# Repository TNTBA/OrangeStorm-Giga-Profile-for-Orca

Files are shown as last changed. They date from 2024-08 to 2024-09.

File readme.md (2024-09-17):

# System profile for Orca Slicer
orca-screenshot

# 9/17/2024 - I have decided to stop working on this project. Elegoo has a fork of Orcaslicer which has print profiles which are much better than what you'll find here. Check it out: https://github.com/ELEGOOTechSupport/ElegooSlicer  Read more here: https://tntba.com/giga-tap-orangestorm-giga-probe-mod/

**Currently this profile works ONLY after making changes to your printer.cfg file in klipper.**
**This is only for Elegoo Printers who are using a single hotend. If you are using more than one hotend (IDEX configuration), do not use this configuration.** 

Enter into Fluidd (the UI for your printer/klipper) so you can access klipper and your config files. 

To do this, you would go to your computer's browser and enter the ip address for your 3d printer. Your printer's ip address can be found by looking at the printer's screen in a config section somewhere. 

ex. 192.168.xxx.xxx/#

After logging in, go to your printer's configuration tab. 

Find your "printer.cfg". right click the file and rename it. You should rename to something like: "printer-elegoo.cfg". we do not want to delete this because you may want to go back to this if you dont like my printer.cfg. 

download the included printer.cfg from this github and upload it to fluidd. This will act as your new config file. 
download the orca_variables.cfg from this github and upload it to fluidd.

if everything is uploaded, restart klipper from the Fluid UI screen. 

# WINDOWS INSTALLATION:
## ORCA SLICER PROFILE INSTALLATION INSTRUCTIONS
You will need the following files to make this work:

### Main Manufacturer Config file:
#### 1. orca_slicer_config\profiles\Elegoo.json

On windows:You will require admin privileges in order to do this.  Go to "C:\Program Files\OrcaSlicer\resources\profiles" from windows explorer. You will see there is already an "Elegoo.json". Rename this file as "Elegoo original.json" or save it in another location on your computer in case you wish to revert back one day. Save the Elegoo.json file from this github to that location. 

### Build Plate SVG & STL
#### 1. orca_slicer_config\profiles\Elegoo\elegoo_orangestorm_giga_buildplate_model.stl
#### 2. orca_slicer_config\profiles\Elegoo\giga_plate-02.svg

On Windows: Go to "C:\Program Files\OrcaSlicer\resources\profiles\Elegoo"
You will save the two files in this directory. You will not overwrite anything. 

Save these two files in the following location: 
C:\Program Files\OrcaSlicer\resources\profiles\Elegoo

### Process files:
#### 1. orca_slicer_config\profiles\Elegoo\process\fdm_process_orangestorm_common.json
#### 2. orca_slicer_config\profiles\Elegoo\process\0.20mm Standard @Elegoo Orangestorm Giga (0.4 nozzle).json
#### 3. orca_slicer_config\profiles\Elegoo\process\0.20mm Standard @Elegoo Orangestorm Giga (0.6 nozzle).json
#### 4. orca_slicer_config\profiles\Elegoo\process\0.20mm Standard @Elegoo Orangestorm Giga (0.8 nozzle).json
#### 5. orca_slicer_config\profiles\Elegoo\process\0.20mm Standard @Elegoo Orangestorm Giga (1.0 nozzle).json

On Windows: Go to "C:\Program Files\OrcaSlicer\resources\profiles\Elegoo\process" and save the above github files to this location. 

### Machine Profiles:
#### 1. orca_slicer_config\profiles\Elegoo\machine\fdm_orangestorm_giga_common.json
#### 2. orca_slicer_config\profiles\Elegoo\machine\Elegoo Orangestorm Giga (0.4 nozzle).json
#### 3. orca_slicer_config\profiles\Elegoo\machine\Elegoo Orangestorm Giga (0.6 nozzle).json
#### 4. orca_slicer_config\profiles\Elegoo\machine\Elegoo Orangestorm Giga (0.8 nozzle).json
#### 5. orca_slicer_config\profiles\Elegoo\machine\Elegoo Orangestorm Giga (1.0 nozzle).json

On Windows: Go to "C:\Program Files\OrcaSlicer\resources\profiles\Elegoo\machine" and save the above github files to this location. 

### Filament Profiles:
#### 1. orca_slicer_config\profiles\Elegoo\filament\Elegoo Generic ABS.json
#### 2. orca_slicer_config\profiles\Elegoo\filament\Elegoo Generic PETG.json
#### 3. orca_slicer_config\profiles\Elegoo\filament\Elegoo Generic PLA.json

On Windows: Go to "C:\Program Files\OrcaSlicer\resources\profiles\Elegoo\filament" and save the above github files to this location. 
You may want to save the Elegoo Generic profiles located in the folder before overwriting them with mine - its up to you. 

### Final steps:
With those files in their appropriate directories, close Orcaslicer. Then go you will then need to go to "C:\Users\YOUR_USER_NAME\AppData\Roaming\OrcaSlicer\system" and delete the "C:\Users\YOUR_USER_NAME\AppData\Roaming\OrcaSlicer\system\Elegoo.json" file in that location. 

Try loading up Orca Slicer and go to printer selection, search for Elegoo, scroll toward the bottom to see Orangestorm Giga and the 4 nozzle profiles. Select whichever one you intend on using and enjoy!

If this does not work, close Orca Slicer and go back to "C:\Users\YOUR_USER_NAME\AppData\Roaming\OrcaSlicer\system" and delete:
Elegoo.json & the entire Elegoo directory.

# MAC OSX INSTRUCTIONS

On Mac, open a Finder window and navigation to Applications. Right click on OrcaSlicer and click on Show Package Contents. You will be presented with Contents, double click on that folder, then double click on Resources, then double click on profiles. From here you can save the above files. Your 'orca_slicer_config' path should be this be default: "/Applications/OrcaSlicer.app/Contents/Resources/".

Relaunch, if OrcaSlicer is open, otherwise open OrcaSlicer and you will now have the Orangestorm Giga profiles. 

**Please note that by deleting the Elegoo directory, you may lose custom print profiles you have created with your other elegoo machines. I have not tested this to see whether that would be the case since the Orangestorm Giga is my first Elegoo printer.** 

Special thanks to secprepper for the Mac OSX instructions

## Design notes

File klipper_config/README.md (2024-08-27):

# WHY DID I DO THIS???
Orca does not have any available configurations that enables the use of multiple heatbeds. If it does, then i'm an idiot. If I'm right, then what this code will do is figure out where the models were placed on your slicer and send that information to klipper to figure out which heatbeds to turn on and off. 
                                                        
# Updated Macros:
1. M140 - Now handles multiple heatbeds. If a T# parameter is provided, it controls the specified bed heater. Otherwise, it uses min/max coordinates to determine which beds to heat.
2. M190 - Updated to correctly reference sensors for each heater bed and wait appropriately based on bed coordinates or the T# parameter.
3. PRINT_END - Enhanced to perform comprehensive shutdown procedures, including clearing min/max XYZ variables, turning off all heaters, fans, and steppers.
4. PAUSE - Modified to save the current print state, including extruder position and temperatures, to enable proper resumption.
5. RESUME - Updated to restore the printer state after a pause, including extruder and bed temperatures.
6. CANCEL_PRINT - Improved to clear the print state, stop all movements, and turn off heaters, fans, and steppers as necessary.

# Notes:
- Make sure to include the orca_variables.cfg file as it contains the necessary variable definitions for the M140, M190, and PRINT_END macros. It took a lot of time and patience to get this working thanks to ChatGPT.

Follow me for other 3D printer related stuff www.tntba.com
- TryNotToBreakAnything
  
I've placed the macros you will need to overwrite or copy and paste in your printer.cfg. You can keep old macros in the same file if you want by including a semicolon ";" before each line of code - which you will see in my printer.cfg

```
[include orca_variables.cfg]
```
```
[gcode_macro RESUME]
rename_existing: BASE_RESUME
variable_flag_print_status: 1
variable_zhop: 0
variable_etemp: 0
variable_bed_temp: 0
variable_bed_temp1: 0
variable_bed_temp2: 0
variable_bed_temp3: 0
variable_saved_x: 0.0
variable_saved_y: 0.0
variable_saved_z: 0.0
variable_saved_e: 0.0
gcode:
    {% if flag_print_status > 0.5 %}
    M25
    {% set e = params.E|default(2)|int %}   
    SET_IDLE_TIMEOUT TIMEOUT={printer.configfile.settings.idle_timeout.timeout}
    SET_HEATER_TEMPERATURE HEATER=extruder TARGET={etemp}
    SET_HEATER_TEMPERATURE HEATER=heater_bed TARGET={bed_temp}
    SET_HEATER_TEMPERATURE HEATER=heater_bed1 TARGET={bed_temp1}
    SET_HEATER_TEMPERATURE HEATER=heater_bed2 TARGET={bed_temp2}
    SET_HEATER_TEMPERATURE HEATER=heater_bed3 TARGET={bed_temp3}
    {% if printer[printer.toolhead.extruder].temperature < etemp-4 %}
      TEMPERATURE_WAIT SENSOR=extruder MINIMUM={etemp-4} MAXIMUM={etemp+50}
    {% endif %}
    M400
    G91
    M83
    G1 E100 F200	
    G4 P2000	
    G1 X-20 F15000
    G1 X20
    G1 X-20
    G1 X20
    G1 X-20
    G1 X20
    G90
    G92 E{saved_e}
    M400
    SET_GCODE_VARIABLE MACRO=RESUME VARIABLE=flag_print_status VALUE="{0}"
    M400
    SET_GCODE_VARIABLE MACRO=PAUSE VARIABLE=flag_print_status VALUE="{1}"
    M400
    RESTORE_GCODE_STATE NAME=timelapse_state_b MOVE=1 MOVE_SPEED=250
    M400
    RESTORE_GCODE_STATE NAME=timelapse_state_a MOVE=1 MOVE_SPEED=50	
    M400
    M24
    {% else %}
    M400
    {% endif %}
```
```
[gcode_macro PRINT_START]         
gcode:
    SET_GCODE_VARIABLE MACRO=RESUME VARIABLE=flag_print_status VALUE="{0}"
    M400
    SET_GCODE_VARIABLE MACRO=PAUSE VARIABLE=flag_print_status VALUE="{1}"
    M400
    SAVE_VARIABLE VARIABLE=was_interrupted VALUE=True
	G92 E0
    BED_MESH_CLEAR                                           
	G90
    BED_MESH_PROFILE LOAD=default   
    CLEAR_PAUSE
    # C1  
    M117 Printing
```

```
[gcode_macro PRINT_END]
gcode:
    SAVE_VARIABLE VARIABLE=was_interrupted VALUE=False
    RUN_SHELL_COMMAND CMD=clear_plr
    clear_last_file
    # Clear min/max XYZ variables
    SET_GCODE_VARIABLE MACRO=HEATBED_CONTROL VARIABLE=min_x VALUE="0.0"
    SET_GCODE_VARIABLE MACRO=HEATBED_CONTROL VARIABLE=min_y VALUE="0.0"
    SET_GCODE_VARIABLE MACRO=HEATBED_CONTROL VARIABLE=min_z VALUE="0.0"
    SET_GCODE_VARIABLE MACRO=HEATBED_CONTROL VARIABLE=max_x VALUE="0.0"
    SET_GCODE_VARIABLE MACRO=HEATBED_CONTROL VARIABLE=max_y VALUE="0.0"
    SET_GCODE_VARIABLE MACRO=HEATBED_CONTROL VARIABLE=max_z VALUE="0.0"
    {% set RUN_VELOCITY = printer.configfile.settings['printer'].max_velocity|float %}
    {% set RUN_ACCEL    = printer.configfile.settings['printer'].max_accel|float %}
    {% set RUN_DECEL    = printer.configfile.settings['printer'].max_accel_to_decel|float %}
    M400
    SET_GCODE_VARIABLE MACRO=RESUME VARIABLE=flag_print_status VALUE="0"
    M400
    SET_GCODE_VARIABLE MACRO=PAUSE VARIABLE=flag_print_status VALUE="1"
    M400
    SET_VELOCITY_LIMIT VELOCITY={RUN_VELOCITY} ACCEL={RUN_ACCEL} ACCEL_TO_DECEL={RUN_DECEL}
    M220 S100
    M221 S100
    {% set z = params.Z|default(200)|int %}
    {% if (printer.gcode_move.position.z+10) < z %}
      G90
      G1 Z{z+10} F6000
    {% endif %}
    G91 ;Relative positioning
    M83
    G1 E-2 F2700 ;Retract a bit
    G1 X5 Y5 E-8 Z3 F2400 ;Retract and raise Z
    G90 ;Absolute positioning
    G1 X20 Y20 F9000 ;Present print
    TURN_OFF_HEATERS
    M106 S0 ;Turn off fan
    M104 S0 ;Turn off hotend
    M140 S0 ;Turn off bed
    M84 X Y E ;Disable all steppers but Z
    M107
    M84
```
```
[gcode_macro CANCEL_PRINT]
rename_existing: BASE_CANCEL_PRINT
variable_flag_home_x: 0
variable_flag_home_y: 0
gcode:
    SAVE_VARIABLE VARIABLE=was_interrupted VALUE=False
    RUN_SHELL_COMMAND CMD=clear_plr
    clear_last_file
    # Clear min/max XYZ variables
    SET_GCODE_VARIABLE MACRO=HEATBED_CONTROL VARIABLE=min_x VALUE=""
    SET_GCODE_VARIABLE MACRO=HEATBED_CONTROL VARIABLE=min_y VALUE=""
    SET_GCODE_VARIABLE MACRO=HEATBED_CONTROL VARIABLE=min_z VALUE=""
    SET_GCODE_VARIABLE MACRO=HEATBED_CONTROL VARIABLE=max_x VALUE=""
    SET_GCODE_VARIABLE MACRO=HEATBED_CONTROL VARIABLE=max_y VALUE=""
    SET_GCODE_VARIABLE MACRO=HEATBED_CONTROL VARIABLE=max_z VALUE=""
    M400
    SET_GCODE_VARIABLE MACRO=RESUME VARIABLE=flag_print_status VALUE="{0}"
    M400
    SET_GCODE_VARIABLE MACRO=PAUSE VARIABLE=flag_print_status VALUE="{1}"
    M400
    {% set RUN_VELOCITY = printer.configfile.settings['printer'].max_velocity|float %}
    {% set RUN_ACCEL    = printer.configfile.settings['printer'].max_accel|float %}
    {% set RUN_DECEL    = printer.configfile.settings['printer'].max_accel_to_decel|float %}
    SET_VELOCITY_LIMIT VELOCITY={RUN_VELOCITY} ACCEL={RUN_ACCEL} ACCEL_TO_DECEL={RUN_DECEL}
    {% set z = params.Z|default(200)|int %}
    {% set x_park = params.X|default(printer.toolhead.axis_minimum.x+30)|int %}
    {% set y_park = params.Y|default(printer.toolhead.axis_minimum.y+30)|int %}
    SET_IDLE_TIMEOUT TIMEOUT={printer.configfile.settings.idle_timeout.timeout}
    SDCARD_RESET_FILE
    M220 S100
    M221 S100
    {%if flag_home_x > 0.5 and flag_home_y > 0.5%}
      M400
      M83
      G1 E-2.0 F1200
      {%if (printer.gcode_move.position.z+10) < z %}
      G90 
      G1 X{x_park} Y{y_park} Z{z+10} F6000 
      {% else %}
      G91
      G1 Z5 F600
      G90 
      G1 X{x_park} Y{y_park} F6000 
      {% endif %}
    {% else %}
    G91
    G1 Z5 F600
    {% endif %}        
    TURN_OFF_HEATERS
    M107
    G90
    M82
    M84
```

```
[gcode_macro PAUSE]
rename_existing: BASE_PAUSE
variable_flag_print_status: 1
variable_flag_home_x: 0
variable_flag_home_y: 0
gcode:
    {%if flag_home_x > 0.5 and flag_home_y > 0.5%}
      {% if flag_print_status > 0.5 %}
        M400  
      {% set z = params.Z|default(200)|int %}                                                   
      {% set E = (params.E|default(2))|float %}
      {% set x_park = params.X|default(printer.toolhead.axis_minimum.x+30)|int %} 
      {% set y_park = params.Y|default(printer.toolhead.axis_minimum.y+30)|int %} 
        M400
      {% set position = printer.gcode_move.gcode_position %}
        SET_GCODE_VARIABLE MACRO=RESUME VARIABLE=saved_x VALUE="{position.x}"
        SET_GCODE_VARIABLE MACRO=RESUME VARIABLE=saved_y VALUE="{position.y}"
        SET_GCODE_VARIABLE MACRO=RESUME VARIABLE=saved_z VALUE="{position.z}"
        SET_GCODE_VARIABLE MACRO=RESUME VARIABLE=saved_e VALUE="{position.e}"
      {% if printer[printer.toolhead.extruder].temperature > 150 %}
        SET_GCODE_VARIABLE MACRO=RESUME VARIABLE=etemp VALUE={printer['extruder'].target}
      {% endif %}
        SET_GCODE_VARIABLE MACRO=RESUME VARIABLE=bed_temp VALUE={printer['heater_bed'].target}
        SET_GCODE_VARIABLE MACRO=RESUME VARIABLE=bed_temp1 VALUE={printer['heater_generic heater_bed1'].target}
        SET_GCODE_VARIABLE MACRO=RESUME VARIABLE=bed_temp2 VALUE={printer['heater_generic heater_bed2'].target}
        SET_GCODE_VARIABLE MACRO=RESUME VARIABLE=bed_temp3 VALUE={printer['heater_generic heater_bed3'].target}
        SAVE_GCODE_STATE NAME=timelapse_state_a
        M83
        G91
        G1 E-2 X3 Z1 F2100
        G1 Z4 F600
        SAVE_GCODE_STATE NAME=timelapse_state_b
        G90
      {% if (printer.gcode_move.position.z+10) < z %} 
        G1 Z{z+10} X{x_park} Y{y_park} E-20 F6000 
      {% else %}
        G1 X{x_park} Y{y_park} E-20 F6000
      {% endif %}
        M400
        SET_GCODE_VARIABLE MACRO=PAUSE VARIABLE=flag_print_status VALUE="{0}"
        M400
        SET_GCODE_VARIABLE MACRO=RESUME VARIABLE=flag_print_status VALUE="{1}"
        M25
        SET_IDLE_TIMEOUT TIMEOUT=1800
        M400
      {% endif %}
    {% endif %}
```

```
[gcode_macro M140]
rename_existing: M140.6245197
gcode:
    {% if "T" in params %}
        {% set heater_bed = "heater_bed" ~ params.T|replace('0', '') %}
        SET_HEATER_TEMPERATURE HEATER={heater_bed} TARGET={params.S|int}
    {% else %}
        {% set min_x = printer["gcode_macro HEATBED_CONTROL"].min_x|float %}
        {% set min_y = printer["gcode_macro HEATBED_CONTROL"].min_y|float %}
        {% set max_x = printer["gcode_macro HEATBED_CONTROL"].max_x|float %}
        {% set max_y = printer["gcode_macro HEATBED_CONTROL"].max_y|float %}
        {% set temp = params.S|int %}

        {% if min_x < 405 and min_y < 402.5 %}
            SET_HEATER_TEMPERATURE HEATER=heater_bed TARGET={temp}  ; Heatbed 0 (Bottom Left)
        {% endif %}
        {% if max_x >= 405 and min_y < 402.5 %}
            SET_HEATER_TEMPERATURE HEATER=heater_bed1 TARGET={temp} ; Heatbed 1 (Bottom Right)
        {% endif %}
        {% if max_x >= 405 and max_y >= 402.5 %}
            SET_HEATER_TEMPERATURE HEATER=heater_bed2 TARGET={temp} ; Heatbed 2 (Top Right)
        {% endif %}
        {% if min_x < 405 and max_y >= 402.5 %}
            SET_HEATER_TEMPERATURE HEATER=heater_bed3 TARGET={temp} ; Heatbed 3 (Top Left)
        {% endif %}
    {% endif %}
```
```
[gcode_macro M190]
rename_existing: M190.6245197
gcode:
    {% if "T" in params %}
        {% set heater_bed = "heater_bed" ~ params.T|replace('0', '') %}
        TEMPERATURE_WAIT SENSOR={heater_bed} MINIMUM={params.S|int-2} MAXIMUM={params.S|int+2}
    {% else %}
        {% set min_x = printer["gcode_macro HEATBED_CONTROL"].min_x|float %}
        {% set min_y = printer["gcode_macro HEATBED_CONTROL"].min_y|float %}
        {% set max_x = printer["gcode_macro HEATBED_CONTROL"].max_x|float %}
        {% set max_y = printer["gcode_macro HEATBED_CONTROL"].max_y|float %}
        {% set temp = params.S|int %}

        {% if min_x < 405 and min_y < 402.5 %}
            TEMPERATURE_WAIT SENSOR=heater_bed MINIMUM={temp-2} MAXIMUM={temp+2}  ; Wait for Heatbed 0
        {% endif %}
        {% if max_x >= 405 and min_y < 402.5 %}
            TEMPERATURE_WAIT SENSOR="heater_generic heater_bed1" MINIMUM={temp-2} MAXIMUM={temp+2} ; Wait for Heatbed 1
        {% endif %}
        {% if max_x >= 405 and max_y >= 402.5 %}
            TEMPERATURE_WAIT SENSOR="heater_generic heater_bed2" MINIMUM={temp-2} MAXIMUM={temp+2} ; Wait for Heatbed 2
        {% endif %}
        {% if min_x < 405 and max_y >= 402.5 %}
            TEMPERATURE_WAIT SENSOR="heater_generic heater_bed3" MINIMUM={temp-2} MAXIMUM={temp+2} ; Wait for Heatbed 3
        {% endif %}
    {% endif %}
```

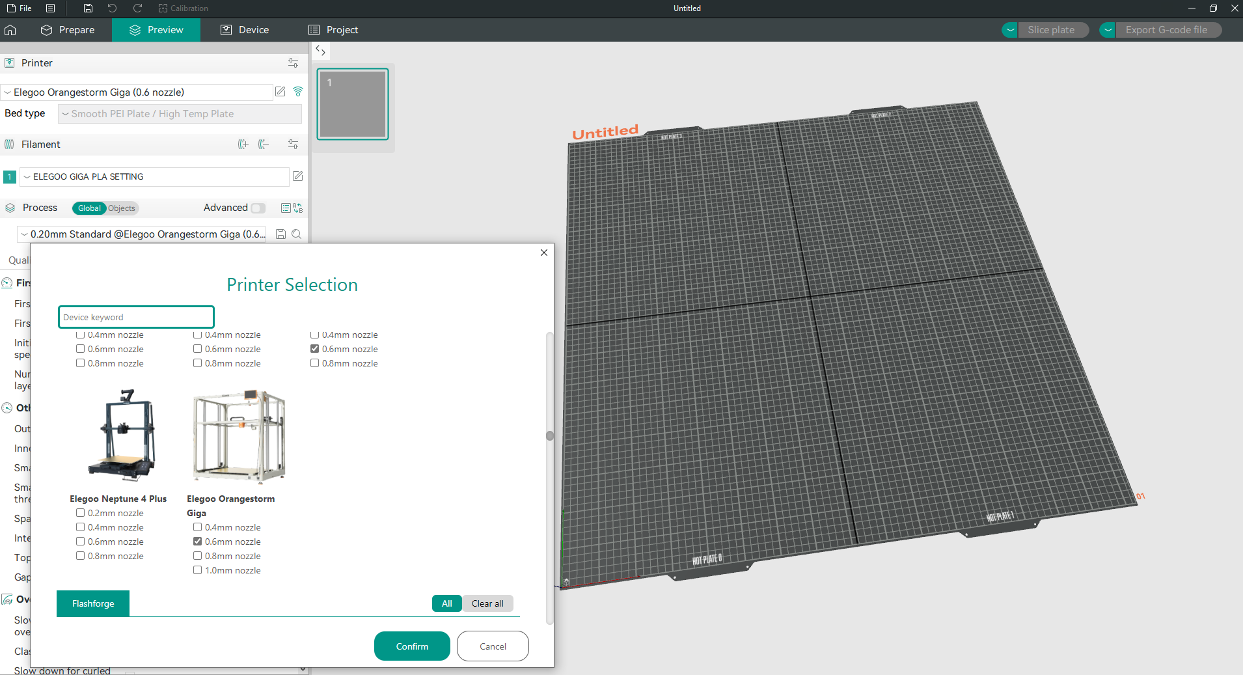
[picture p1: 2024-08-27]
orca-screenshot.png

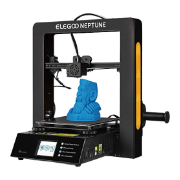
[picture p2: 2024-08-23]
orca_slicer_config/profiles/Elegoo/Elegoo Neptune_cover.png

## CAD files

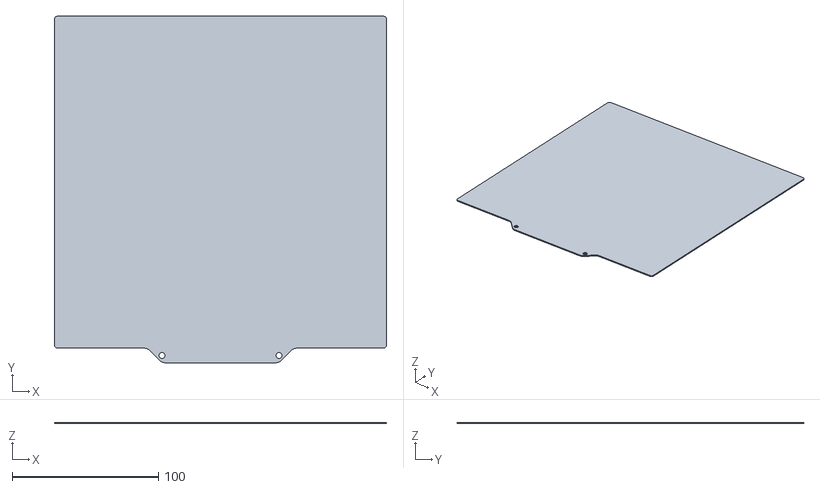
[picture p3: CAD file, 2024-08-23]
orca_slicer_config/profiles/Elegoo/elegoo_neptune3pro_buildplate_model.stl
227.0 x 237.0 x 1.00

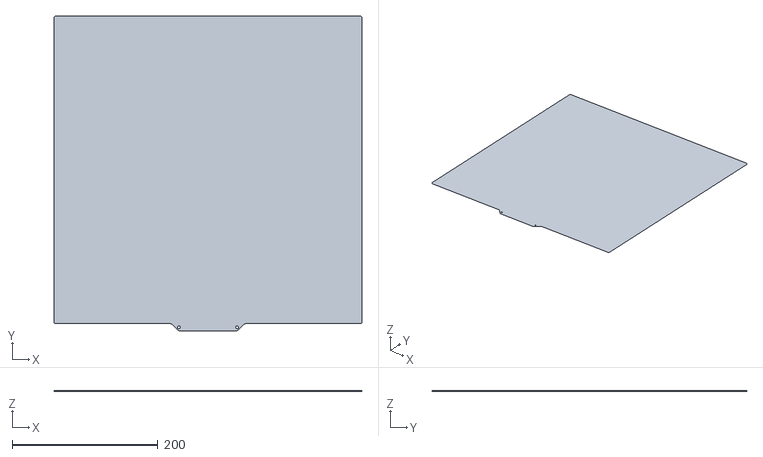
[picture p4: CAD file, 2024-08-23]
orca_slicer_config/profiles/Elegoo/elegoo_neptune4max_buildplate_model.stl
422.0 x 432.0 x 1.00

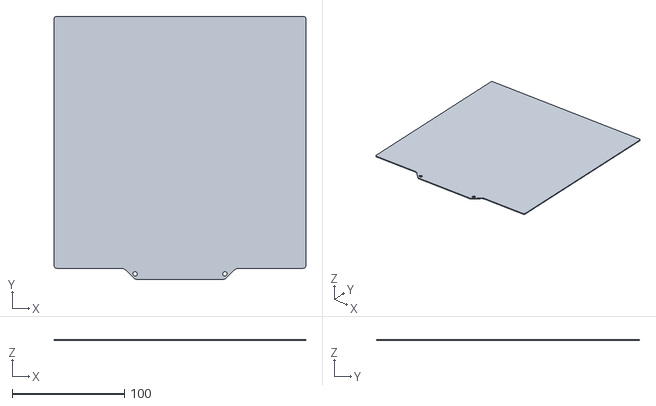
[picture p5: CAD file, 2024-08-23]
orca_slicer_config/profiles/Elegoo/elegoo_neptune2d_buildplate_model.stl
224.0 x 234.0 x 1.00

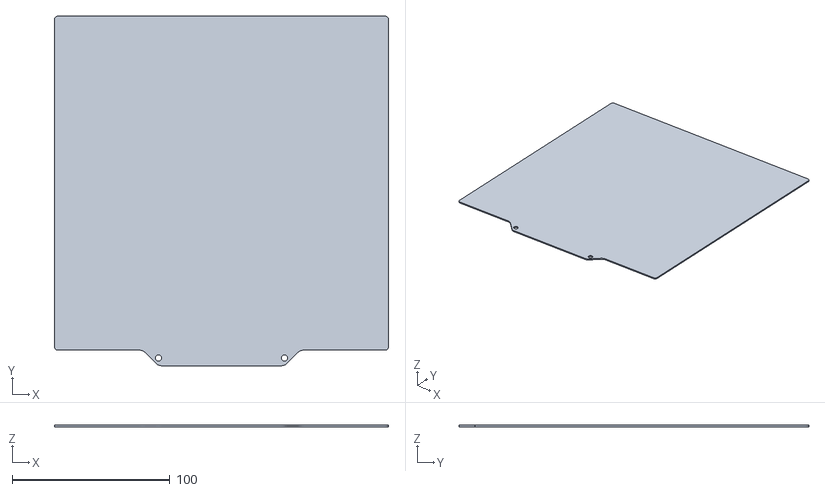
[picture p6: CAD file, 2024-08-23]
orca_slicer_config/profiles/Elegoo/elegoo_neptune_buildplate_model.stl
212.0 x 222.0 x 1.00

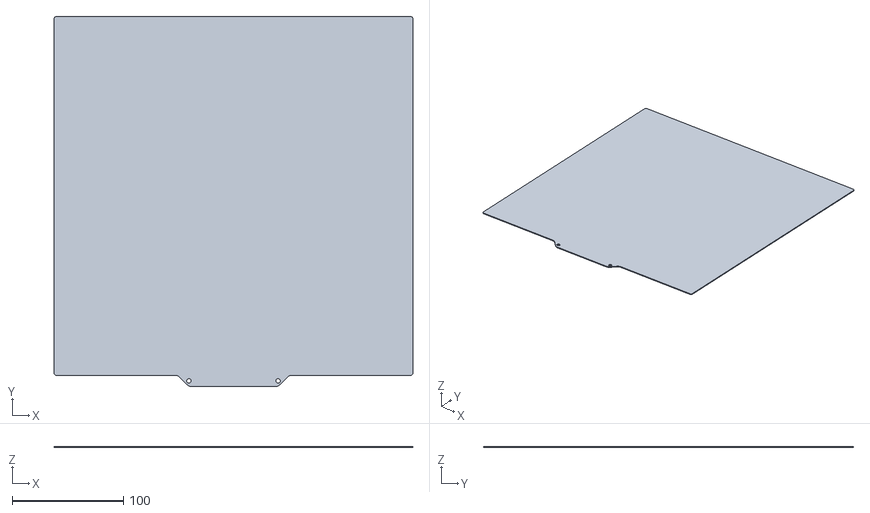
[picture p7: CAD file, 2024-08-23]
orca_slicer_config/profiles/Elegoo/elegoo_neptune3plus_buildplate_model.stl
322.0 x 332.0 x 1.00

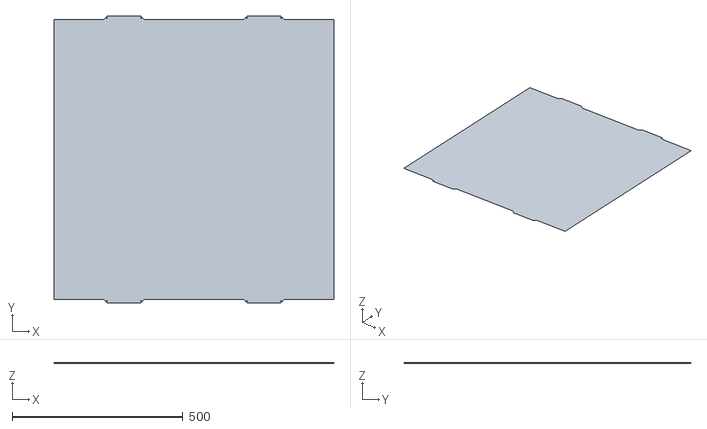
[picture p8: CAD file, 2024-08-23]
orca_slicer_config/profiles/Elegoo/elegoo_orangestorm_giga_buildplate_model.stl
820.0 x 840.0 x 1.00

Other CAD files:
orca_slicer_config/profiles/Elegoo/elegoo_neptune4_buildplate_model.stl
orca_slicer_config/profiles/Elegoo/elegoo_neptune4pro_buildplate_model.stl
orca_slicer_config/profiles/Elegoo/elegoo_neptune3_buildplate_model.stl

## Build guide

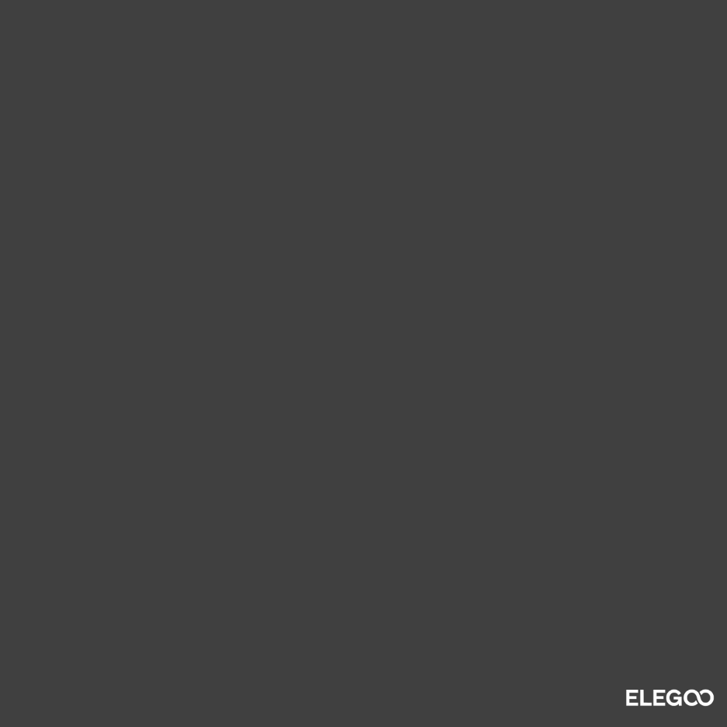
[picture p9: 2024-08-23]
orca_slicer_config/profiles/Elegoo/elegoo_neptune3plus_buildplate_texture.png

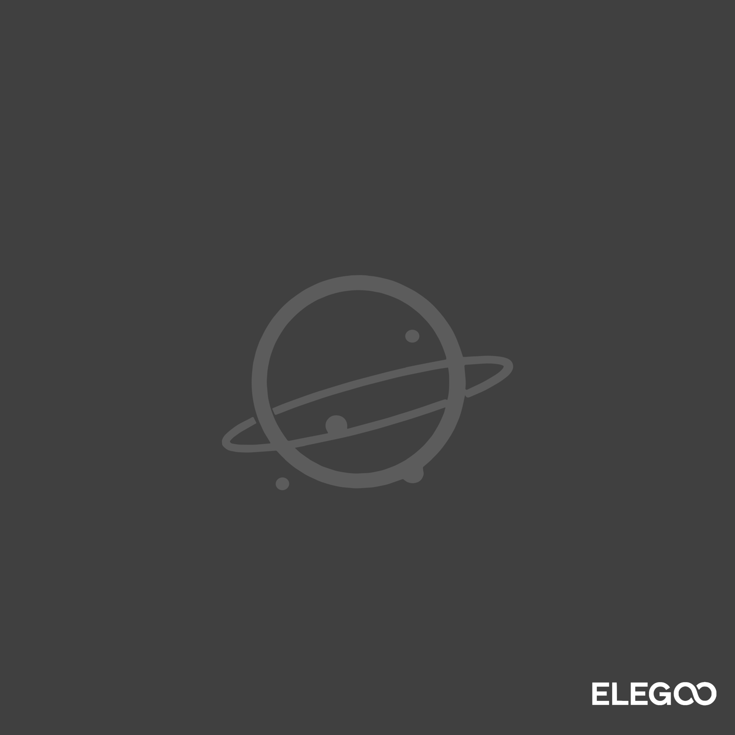
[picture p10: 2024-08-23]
orca_slicer_config/profiles/Elegoo/elegoo_neptune4pro_buildplate_texture.png

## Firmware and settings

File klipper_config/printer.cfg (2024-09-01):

####################################################################################
# Machine type: OrangeStorm Giga
# Current configuration version: V1.2.2
# Date: 2024-08-22
;                          +++                        
;                       +++++                         
;              +       ++++++      ++                 
;              +++    +++++++     ++++                
;               ++++  ++++++++   +++++                
;               +++++++++++++++ +++++++               
;               +++++++++++++++++++++++               
;               ++++++++++++++++++++++++              
;               ++++++++++++++++++++++++              
;              +++++++++++++++++++++++++              
;           ++++++++++++++  +++++++++++++++           
;       +++++++++++++++++   +++++++++++++++++++       
;    ++++++++  +++++++++     ++  +++++++  ++++++++    
;  +++++++    ++++++++++     ++  +++++++      ++++++  
;  +++++++     ++++ ++++          +++++      +++++++  
;  ++++++++++   +++                +++    ++++++++++  
;  +++   +++++++  +                    +++++++   +++  
;  +++      ++++++++               ++++++++      +++  
;  +++          +++++++         +++++++          +++  
;  +++             +++++++   +++++++             +++  
;  +++                +++++++++++                +++  
;  +++                    +++                    +++  
;  +++                    +++                    +++  
;  +++                    +++                    +++  
;  +++                    +++                    +++  
;  +++                    +++                    +++  
;  +++                    +++                    +++  
;  +++                    +++                    +++  
;  +++++++                +++                +++++++  
;    ++++++++             +++             ++++++++    
;       ++++++++          +++          ++++++++       
;          ++++++++       +++       ++++++++          
;              ++++++++   +++   ++++++++              
;                 +++++++++++++++++++                 
;                    +++++++++++++                    
;                       +++++++                       
;                                                     
# WHY DID I DO THIS???
# Orca does not have any available configurations that enables the use of multiple heatbeds.
# If it does, then i'm an idiot. If I'm right, then what this code will do is figure out where
# the models were placed on your slicer and send that information to klipper to figure out which
# heatbeds to turn on and off. 
#                                                          
# Updated Macros:
# 1. M140 - Now handles multiple heatbeds. If a T# parameter is provided, it controls
#    the specified bed heater. Otherwise, it uses min/max coordinates to determine 
#    which beds to heat.
# 2. M190 - Updated to correctly reference sensors for each heater bed and wait 
#    appropriately based on bed coordinates or the T# parameter.
# 3. PRINT_END - Enhanced to perform comprehensive shutdown procedures, including clearing 
#    min/max XYZ variables, turning off all heaters, fans, and steppers.
# 4. PAUSE - Modified to save the current print state, including extruder position and 
#    temperatures, to enable proper resumption.
# 5. RESUME - Updated to restore the printer state after a pause, including extruder 
#    and bed temperatures.
# 6. CANCEL_PRINT - Improved to clear the print state, stop all movements, and turn off 
#    heaters, fans, and steppers as necessary.
# //////////////////// UPDATE v1.2.2 //////////// AUGUST 31ST, 2024 ////////////////////////
# 7. CURRENT INCREASE ON Z STEPPERMOTORS - I have increased the current for stepper_z and stepper_z1 
#    from 1.0 to 1.2. This was done to reduce (eliminate at this point) the z-banding issues I was 
#    experiencing. This increase is within the specs of the TMC2209 drivers as far as temperature 
#    goes. There does not seem to be any significant increases stepper motor or driver temperatures. 

# Notes:
# - Make sure to include the orca_variables.cfg file as it contains the necessary 
#   variable definitions for the M140, M190, and PRINT_END macros.
#
# It took a lot of time and patience to get this working thanks to ChatGPT.
# Follow me for other 3D printer related stuff www.tntba.com
#-TryNotToBreakAnything                                                  
     
####################################################################################
[include orca_variables.cfg]
[include plr.cfg]
[include znp_mcu.cfg]
[include znp_thr1.cfg]

[duplicate_pin_override]
pins:PC0

[stepper_x]
step_pin:PC14
dir_pin:PC13
enable_pin:!PC15
microsteps: 16
rotation_distance: 59.8519
full_steps_per_rotation:200  #set to 400 for 0.9 degree stepper
endstop_pin:PD0
position_min: -5
position_endstop:815
position_max: 815.5
homing_speed:80
homing_retract_dist:10
second_homing_speed:10
homing_positive_dir:true
step_pulse_duration:0.000002

[stepper_y]
step_pin:PE3
dir_pin:PE2
enable_pin:!PE4
microsteps:16
rotation_distance: 59.8519
full_steps_per_rotation:200  #set to 400 for 0.9 degree stepper
gear_ratio: 50:20
endstop_pin:PC12
position_min: -1.0
position_endstop:805.0
position_max:805.5
homing_speed:80
homing_retract_dist:10
second_homing_speed:10
homing_positive_dir:true
step_pulse_duration:0.000002

[stepper_z]
step_pin:PB8
dir_pin:PB7
enable_pin: !PB9
microsteps: 16
rotation_distance: 8
gear_ratio: 50:20
full_steps_per_rotation: 200
endstop_pin:PC11
position_endstop:0
position_max: 1020  # Limit travel: 1050
position_min: -12
homing_speed: 10
second_homing_speed: 3
homing_retract_dist: 5
homing_positive_dir:false

[stepper_z1]
step_pin:PB3
dir_pin:PD7
enable_pin: !PB4
microsteps: 16
rotation_distance: 8
gear_ratio: 50:20
full_steps_per_rotation: 200
endstop_pin:PC10

[verify_heater extruder]
max_error: 30
check_gain_time:10
hysteresis: 10
heating_gain: 2

[heater_bed]
heater_pin:PA3
sensor_type: NTC 100K MGB18-104F39050L32
sensor_pin: PC3
smooth_time: 0.1
control = pid
pid_Kp  = 70.591 
pid_Ki  = 1.055 
pid_Kd  = 1180.632
min_temp: 0
max_temp: 130

[verify_heater heater_bed]
max_error: 600
check_gain_time:120
hysteresis: 10
heating_gain: 2

[heater_generic heater_bed1]
gcode_id:M108
heater_pin:PA2
max_power:1.0
sensor_type: NTC 100K MGB18-104F39050L32
sensor_pin:PC2
smooth_time: 0.1
control = pid
pid_Kp  = 70.591 
pid_Ki  = 1.055 
pid_Kd  = 1180.632
min_temp: 0
max_temp: 130

[verify_heater heater_bed1]
max_error: 600
check_gain_time:120
hysteresis: 10
heating_gain: 2

[heater_generic heater_bed2]
gcode_id:M105
heater_pin:PA1
max_power:1.0
sensor_type: NTC 100K MGB18-104F39050L32
sensor_pin:PC1
smooth_time: 0.1
control = pid
pid_Kp  = 70.591 
pid_Ki  = 1.055 
pid_Kd  = 1180.632
min_temp: 0
max_temp: 130

[verify_heater heater_bed2]
max_error: 600
check_gain_time:120
hysteresis: 10
heating_gain: 2

[heater_generic heater_bed3]
gcode_id:M110
heater_pin:PA0
max_power:1.0
sensor_type: NTC 100K MGB18-104F39050L32
sensor_pin:PC0
smooth_time: 0.1
control = pid
pid_Kp  = 70.591 
pid_Ki  = 1.055 
pid_Kd  = 1180.632
min_temp: 0
max_temp: 130

[verify_heater heater_bed3]
max_error: 600
check_gain_time:120
hysteresis: 10
heating_gain: 2

[printer]
kinematics:cartesian
max_velocity: 500
max_accel: 5000
max_accel_to_decel: 5000
max_z_velocity: 20
max_z_accel: 200
square_corner_velocity: 5.0

#####################################################################
# 	Probe
#####################################################################
[probe]
pin:^mcu1:gpio11
x_offset: -14.0
y_offset: -29.5
z_offset: 0.0
speed: 5.0
samples: 2
samples_result: median
sample_retract_dist: 3.0
samples_tolerance: 0.05
samples_tolerance_retries:4

[bed_mesh]
speed:120                
horizontal_move_z:5     
mesh_min:16,10              
mesh_max:786,767         
probe_count:10,10          
algorithm:bicubic
bicubic_tension:0.2
mesh_pps: 4, 4
fade_start: 1.0
fade_end: 30.0   

[filament_switch_sensor fila]
pause_on_runout: True
runout_gcode:
            SET_FILAMENT_SENSOR SENSOR=fila ENABLE=1
event_delay: 3.0
pause_delay: 0.5
switch_pin: PD4

#Z_TILT_ADJUST
[z_tilt]
z_positions: 
    -50,400
    980,400
points: 
    200,400
    600,400
speed: 50
horizontal_move_z: 5
retries: 10
retry_tolerance: 0.01

########################################
# TMC UART configuration
########################################
[tmc2209 stepper_x]
uart_pin: PE5
run_current: 1.8
hold_current: 1.0
interpolate: False
#interpolate: True
#stealthchop_threshold:99999
# driver_SGTHRS:80
# diag_pin:^PD0

[tmc5160 stepper_y]
cs_pin:PE0
spi_software_sclk_pin:PE12
spi_software_mosi_pin:PE14
spi_software_miso_pin:PE13
spi_speed:200000
run_current: 2.8
hold_current: 1.5
sense_resistor: 0.033
interpolate:False
#interpolate:True
#stealthchop_threshold:99999

[tmc2209 stepper_z]
uart_pin: PB5
run_current: 1.2
hold_current: 1.2
#interpolate: True
#stealthchop_threshold: 120
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

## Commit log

2024-08-22 first version sent
    [printer.cfg, saved_variables.cfg]
2024-08-22 added orca slicer configs that i'm using
    [printer.cfg]
2024-08-23 uploaded the build plate & svg file for the orca profile
    [elegoo_orangestorm_giga_buildplate_model.stl]
2024-08-23 my attempt to make a system profile for orcaslicer and orange storm giga.
    [elegoo_neptune2_buildplate_model.stl, elegoo_neptune2d_buildplate_model.stl, elegoo_neptune2s_buildplate_model.stl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]
2024-08-26 I have included any original orca .json profiles so that I dont lose them as I mess with my own orca profiles. also I updated the custom elegoo.json print profile because nothing was uploaded last ti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
2024-08-26 updated buildplate model to sit properly in slicer
    [elegoo_orangestorm_giga_buildplate_model.stl]
2024-08-26 updated the Elegoo Generic abs, petg, & PLA print profiles
2024-08-26 saving original orca profiles for elegoo filament
2024-08-26 made adjustments to the printer presets
2024-08-27 Adjustments to print speed in fdm_process_orangestorm_common.json
2024-08-27 updated readme and speeds for print profiles
2024-08-27 Added a readme to the klipper section for those who just want to copy and paste code.
    [saved_variables.cfg]
2024-08-27 removed folders
    [elegoo_orangestorm_giga_buildplate_model.stl]
2024-08-27 Update fdm_orangestorm_giga_common.json
    set the printer structure to "hbot" in case that helps.
    modified the machine max jerk settings to match other profiles. I may remove these in the future.
2024-09-01 Update printer.cfg
    # //////////////////// UPDATE v1.2.2 //////////// AUGUST 31ST, 2024 ////////////////////////
    # 7. CURRENT INCREASE ON Z STEPPERMOTORS - I have increased the current for stepper_z and stepper_z1
    # from 1.0 to 1.2. This was done to reduce (eliminate at this point) the z-banding issues I was
    # experiencing. This increase is within the specs of the TMC2209 drivers as far as temperature
    # goes. There does not seem to be any significant increases stepper motor or driver temperatures.
    [printer.cfg]
2024-09-05 Small tweaks to default nozzle configs and enabled Stealthchop for silent X and Z steppers
    [printer.cfg]
2024-09-07 Revert "Improve default nozzle machine configs and silent steppers"
    [printer.cfg]
2024-09-09 fixed profile print area x & y maximums to mirror klipper settings
